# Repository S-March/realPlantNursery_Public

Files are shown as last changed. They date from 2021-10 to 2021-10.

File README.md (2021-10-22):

# realPlantNursery

## Plant Babies
plantBaby

I am REALLY bad at keeping plants alive. I killed a cactus by forgetting to water it once... 

These plant babies sit in the soil of your potted plants and cry like a real baby when they need water (reminding you not to kill them)!

## Tamagotchi mode
tamagotchiMode

Oh, I also made an app for them so you can turn on "tamagotchi" mode and check out all your plants stats!

## Other fun things

Come check out my youtube channel for more fun projects - [youtube.com/c/SamMarch](https://youtube.com/c/SamMarch)

For future projects and progress pictures, follow me on instagram @SamsonMarch

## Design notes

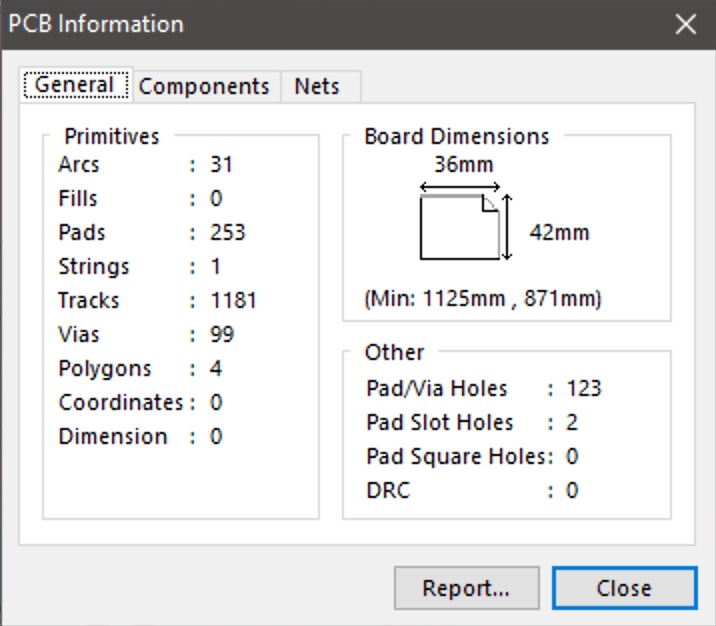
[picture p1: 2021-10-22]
Hardware/realPlantNursery/FabFiles/boardDimensions.jpg

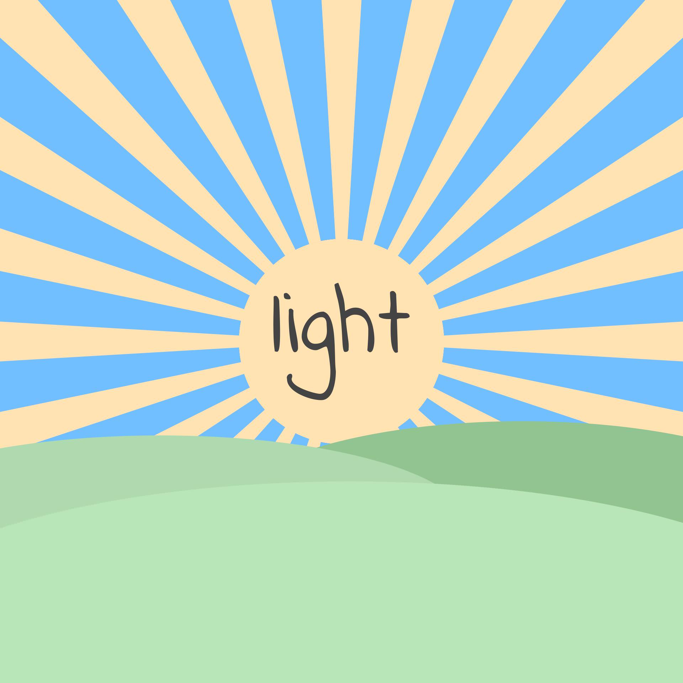
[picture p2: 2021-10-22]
Firmware/sdCardFiles/webPage/projects/lightPage/mediaAssets/imageAssets/main.jpg

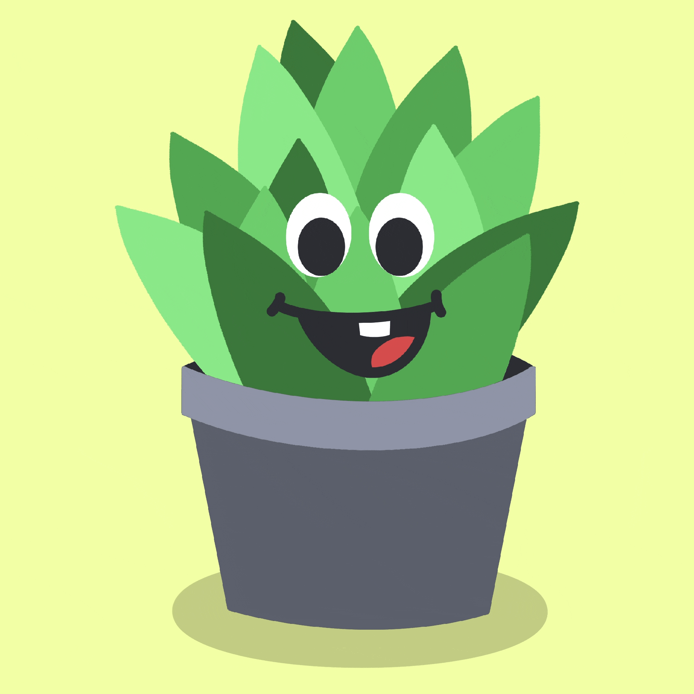
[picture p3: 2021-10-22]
Firmware/sdCardFiles/webPage/projects/mainPage/mediaAssets/imageAssets/main.gif

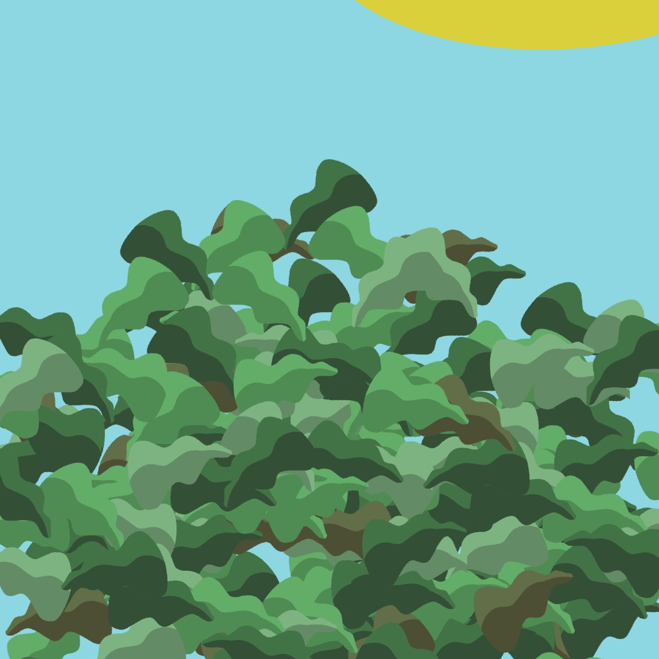
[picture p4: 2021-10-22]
Firmware/sdCardFiles/webPage/projects/lightPage/mediaAssets/imageAssets/lightPlot.jpg

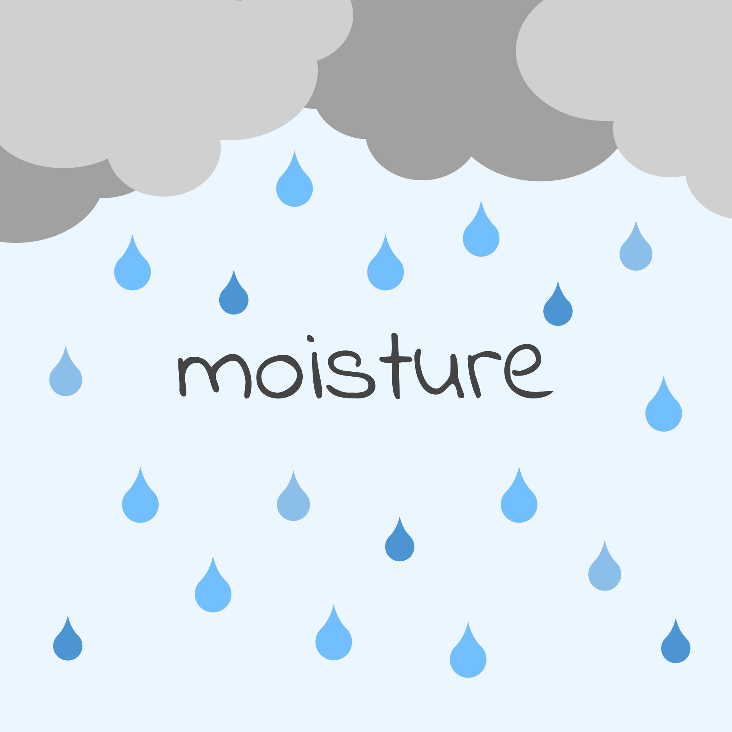
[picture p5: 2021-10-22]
Firmware/sdCardFiles/webPage/projects/moisturePage/mediaAssets/imageAssets/main.jpg

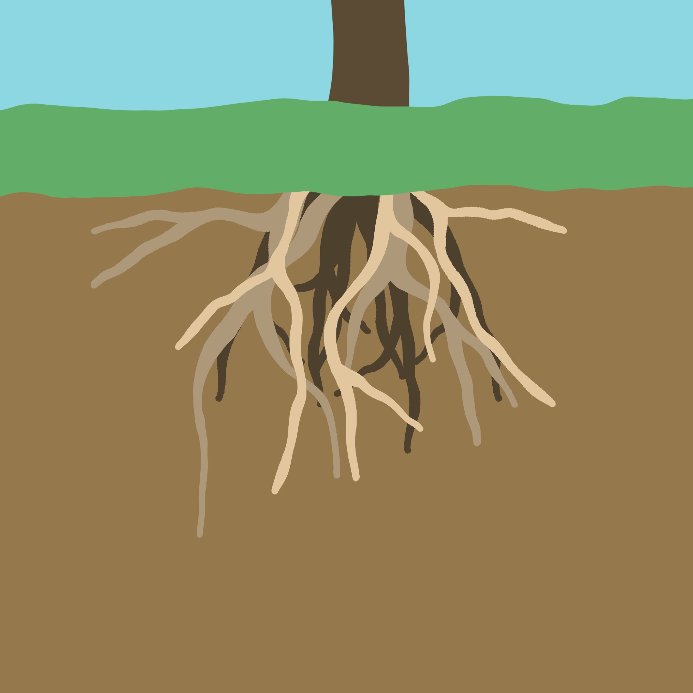
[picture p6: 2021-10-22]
Firmware/sdCardFiles/webPage/projects/moisturePage/mediaAssets/imageAssets/moisturePlot.jpg

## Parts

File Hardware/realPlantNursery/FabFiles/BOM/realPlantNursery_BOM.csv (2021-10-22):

Comment | Designator | Footprint | LCSC Part #（optional）
10k | R2, R4, R5, R6, R7, R8, R9, R10, R11, R12, R15, R16, R17, R18, R19, R20, R22, R23 | 0402_R | C25744
100nF | C2, C3, C4, C5, C7, C10, C15, C18, C19, C20 | 0402_C | C1525
10uF | C1, C6, C13 | 0603_C | C19702
22uF | C14, C16, C17 | 0603_C | C59461
SS34 | D2, D3, D4 | SMA | C408258
K2-1808SN-A4SW-01 | B1, B2 | SMD | C92589
4.7uF | C11, C12 | 0402_C | C23733
1M | R1, R24 | 0402_R | C26083
2450AT18D0100E | ANT1
WS2812B-B | D1 | LED-4_5050 | C114586
YNR3015-2R2M | L1 | SMD_3.0x3.0x1.5mm | C340359
VLS3015ET-3R3M | L2 | IND-SMD | C136236
DM3CS-SF | P1 | TF-SMD | C202111
MicroXNJ | P2 | SMD | C404969
AO3400A | Q1 | SOT-23-3L | C20917
AO3401A | Q2 | SOT-23-3L | C15127
2k | R13 | 0402_R | C4109
75k | R14 | 0402_R | C25798
1k | R21 | 0402_R | C11702
0 | R3 | 0402_R | C17168
MAX98357AETE+T | U1 | TQFN-16 | C910544
TXB0101DCKR | U2 | SC-70-6 | C324081
ESP32-PICO-D4 | U3 | QFN-48_EP_7.0x7.0x0.5P | C193707
TPS62082 | U4 | WDFN-8_EP_2.0x2.0x0.5P | C485809
MCP73832 | U5 | SOT-23-5 | C38066
FP6291LR-G1 | U6 | SOT-23-6L | C18701
BH1721FVC | U7 | WSOF-5 | C184130

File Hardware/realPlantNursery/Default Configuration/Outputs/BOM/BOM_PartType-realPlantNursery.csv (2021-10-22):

Quantity | Designator | Comment | Description
18 | R2, R4, R5, R6, R7, R8, R9, R10, R11, R12, R15, R16, R17, R18, R19, R20, R22, R23 | 10k | 0402 Resistor
10 | C2, C3, C4, C5, C7, C10, C15, C18, C19, C20 | 100nF | 0402 Capacitor
3 | C1, C6, C13 | 10uF | 0603 Capacitor
3 | C14, C16, C17 | 22uF | 0603 Capacitor
3 | D2, D3, D4 | SS34 | SS34 40V 3A 550mV @ 3A SMA(DO-214AC) Schottky Barrier Diodes (SBD) ROHS
2 | B1, B2 | K2-1808SN-A4SW-01 | K2-1808SN-A4SW-01 Tactile Switch SPST-NO Top Actuated Surface Mount
2 | C11, C12 | 4.7uF | 0402 Capacitor
2 | R1, R24 | 1M | 0402 Resistor
1 | ANT1 | 2450AT18D0100E | 2450AT18D0100E 2.4GHz Chip RF Antenna 2.4GHz ~ 2.5GHz 1.5dBi Solder Surface Mount
1 | D1 | WS2812B-B | WS2812B-B RGB 620~630nm Red, 515~530nm Green, 465~475nm Blue SMD,5x5mm Light Emitting Diodes (LED) ROHS
1 | L1 | YNR3015-2R2M | YNR3015-2R2M 2.2uH ±20% 1.6A 30mO SMD,3.0x3.0x1.5mm Power Inductors RoHS
1 | L2 | VLS3015ET-3R3M | VLS3015ET-3R3M 3.3 µH Shielded Wirewound Inductor 1.15 A 112mOhm Max Nonstandard
1 | P1 | DM3CS-SF | DM3CS-SF 10 (8 + 2) Position Card Connector Secure Digital - microSD™ Surface Mount, Right Angle Gold
1 | P2 | MicroXNJ | MicroXNJ USB - micro B USB 2.0 Receptacle Connector 5 Position Surface Mount, Right Angle; Through Hole
1 | Q1 | AO3400A | AO3400A N-Channel 30 V 5.7A (Ta) 1.4W (Ta) Surface Mount SOT-23-3
1 | Q2 | AO3401A | AO3401A MOSFET P-CH 30V 4A SOT23
1 | R13 | 2k | 0402 Resistor
1 | R14 | 75k | 0402 Resistor
1 | R21 | 1k | 0402 Resistor
1 | R3 | 0 | 0402 Resistor
1 | U1 | MAX98357AETE+T | MAX98357AETE+T Amplifier IC 1-Channel (Mono) Class D 16-TQFN (3x3)
1 | U2 | TXB0101DCKR | TXB0101DCKR Voltage Level Translator Bidirectional 1 Circuit 1 Channel 100Mbps SC-70-6
1 | U3 | ESP32-PICO-D4 | ESP32-PICO-D4 SoC
1 | U4 | TPS62082 | TPS62082 Buck Switching Regulator IC Positive Fixed 3.3V 1 Output 1.2A 8-WFDFN Exposed Pad
1 | U5 | MCP73832 | MCP73831 Charger IC Lithium-Ion/Polymer
1 | U6 | FP6291LR-G1 | FP6291LR-G1 2A 5.5V SOT-23-6 DC-DC Converters ROHS
1 | U7 | BH1721FVC | BH1721FVC Optical Sensor Ambient 560nm I²C 5-SMD, Flat Leads

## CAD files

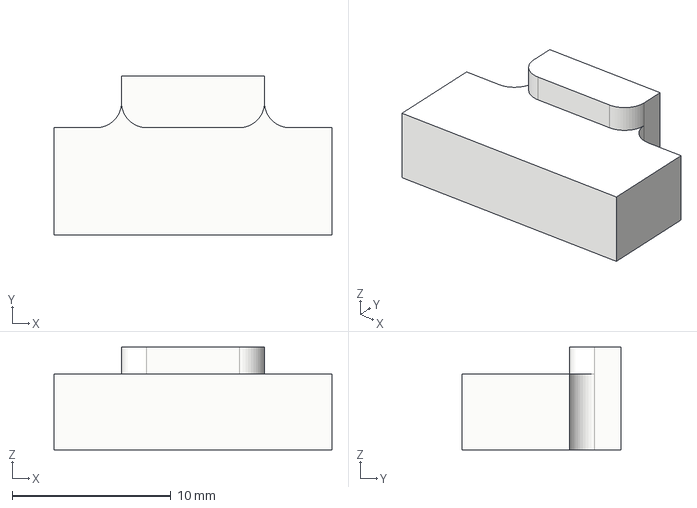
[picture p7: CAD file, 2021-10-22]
CAD/preManufacturing/usbRetainer.step
17.5 x 10.0 x 6.47 mm

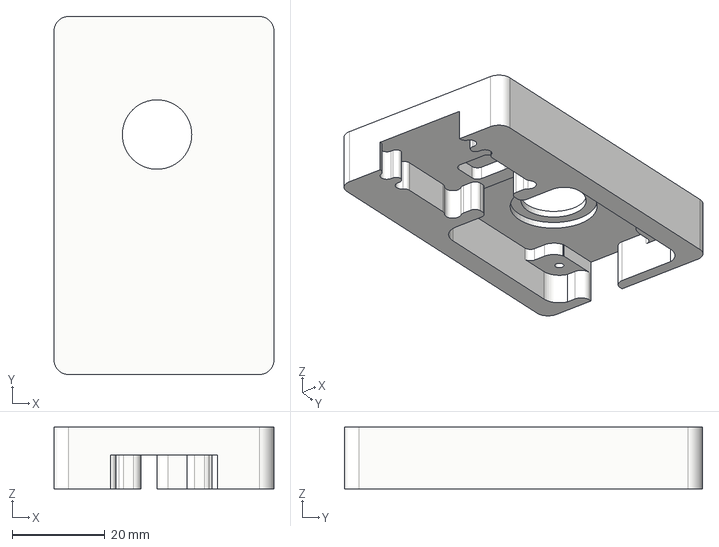
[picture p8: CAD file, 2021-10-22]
CAD/preManufacturing/frontPlate.step
47.5 x 77.3 x 13.3 mm

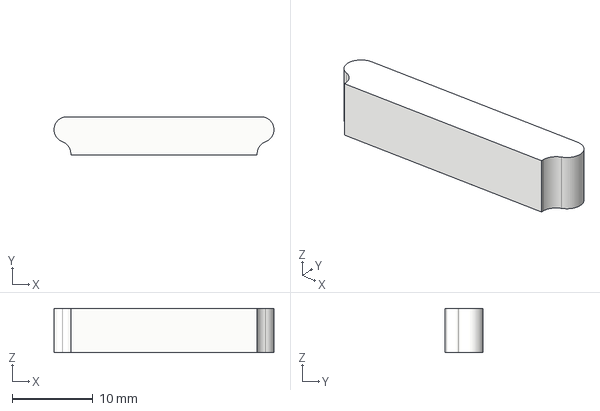
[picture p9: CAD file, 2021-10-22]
CAD/preManufacturing/moistureSensorRetainer.step
27.3 x 4.75 x 5.48 mm

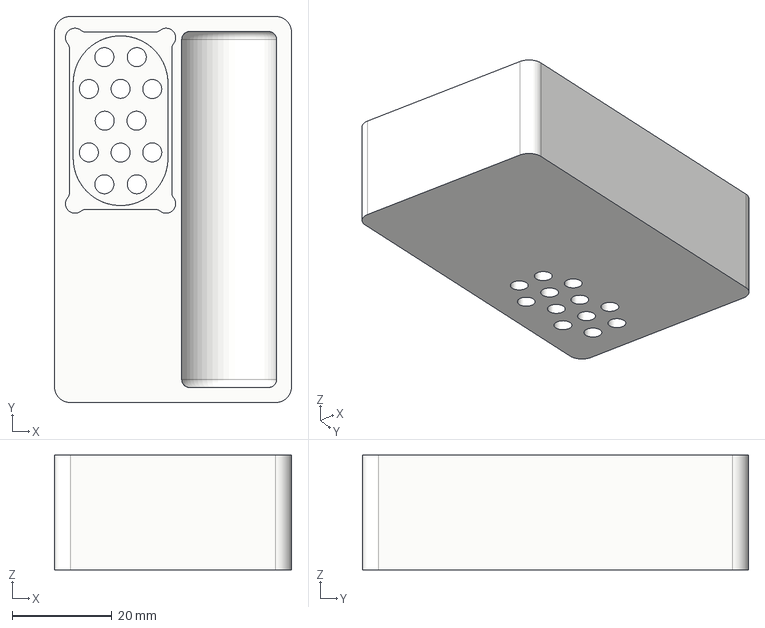
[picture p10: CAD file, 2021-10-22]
CAD/preManufacturing/backPlate.step
47.5 x 77.3 x 23.0 mm

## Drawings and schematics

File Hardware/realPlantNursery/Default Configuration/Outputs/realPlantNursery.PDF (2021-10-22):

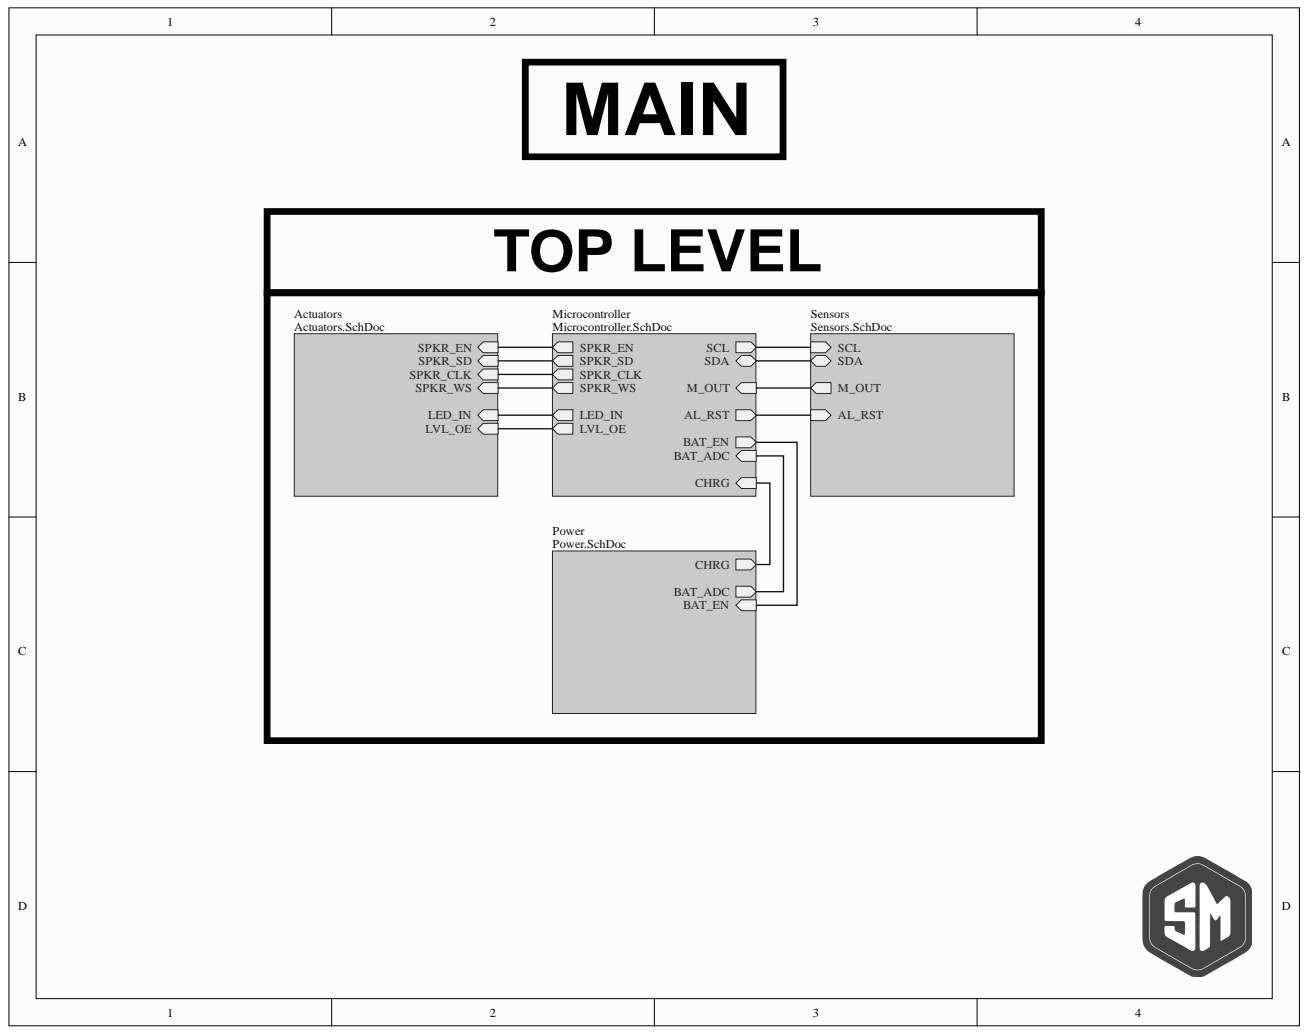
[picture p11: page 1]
TOP LEVEL

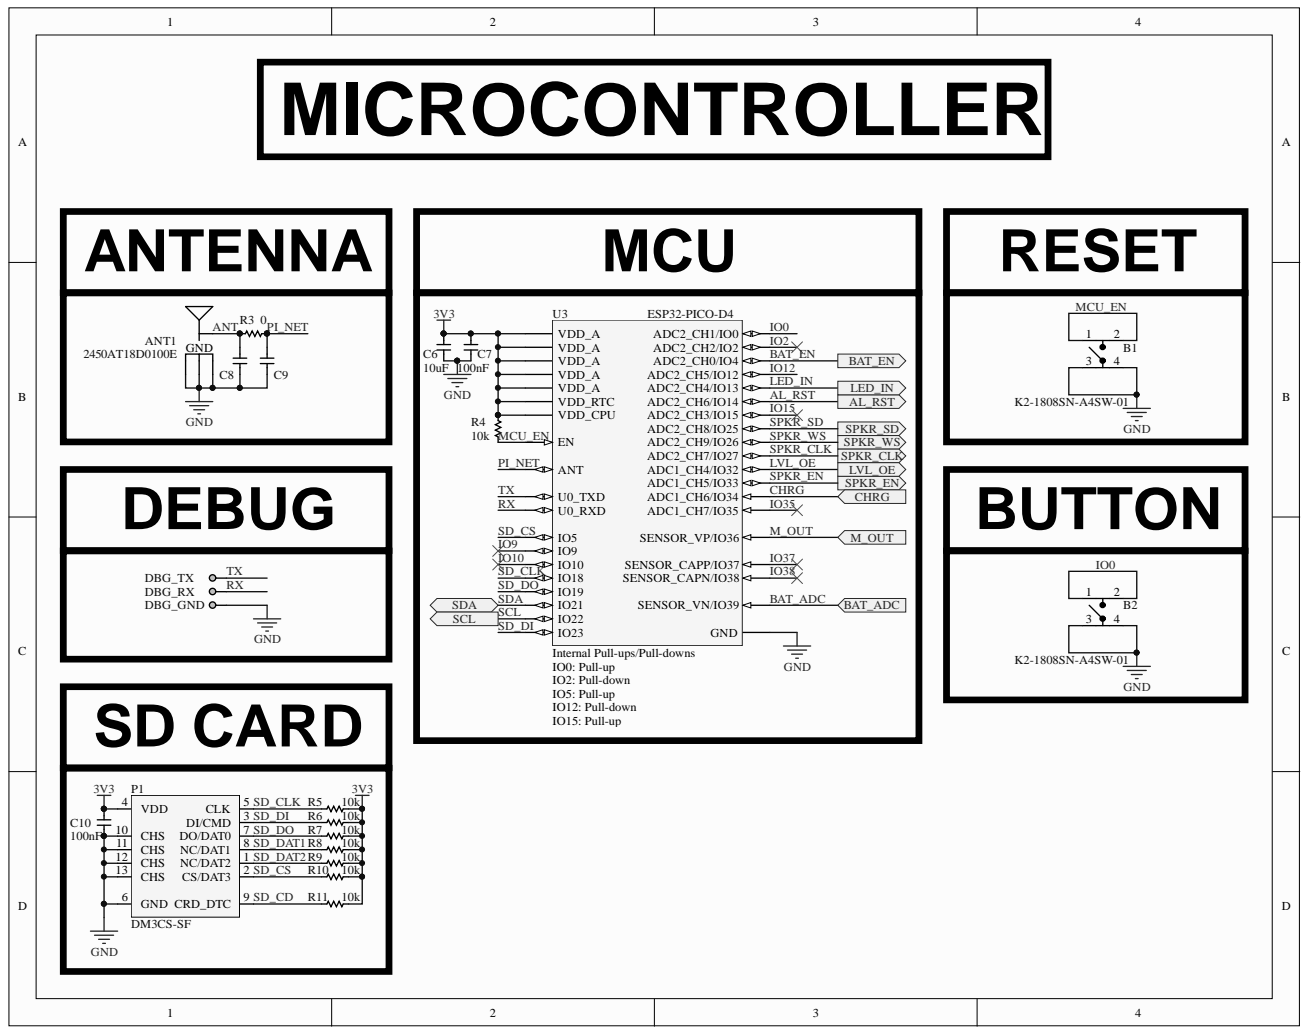
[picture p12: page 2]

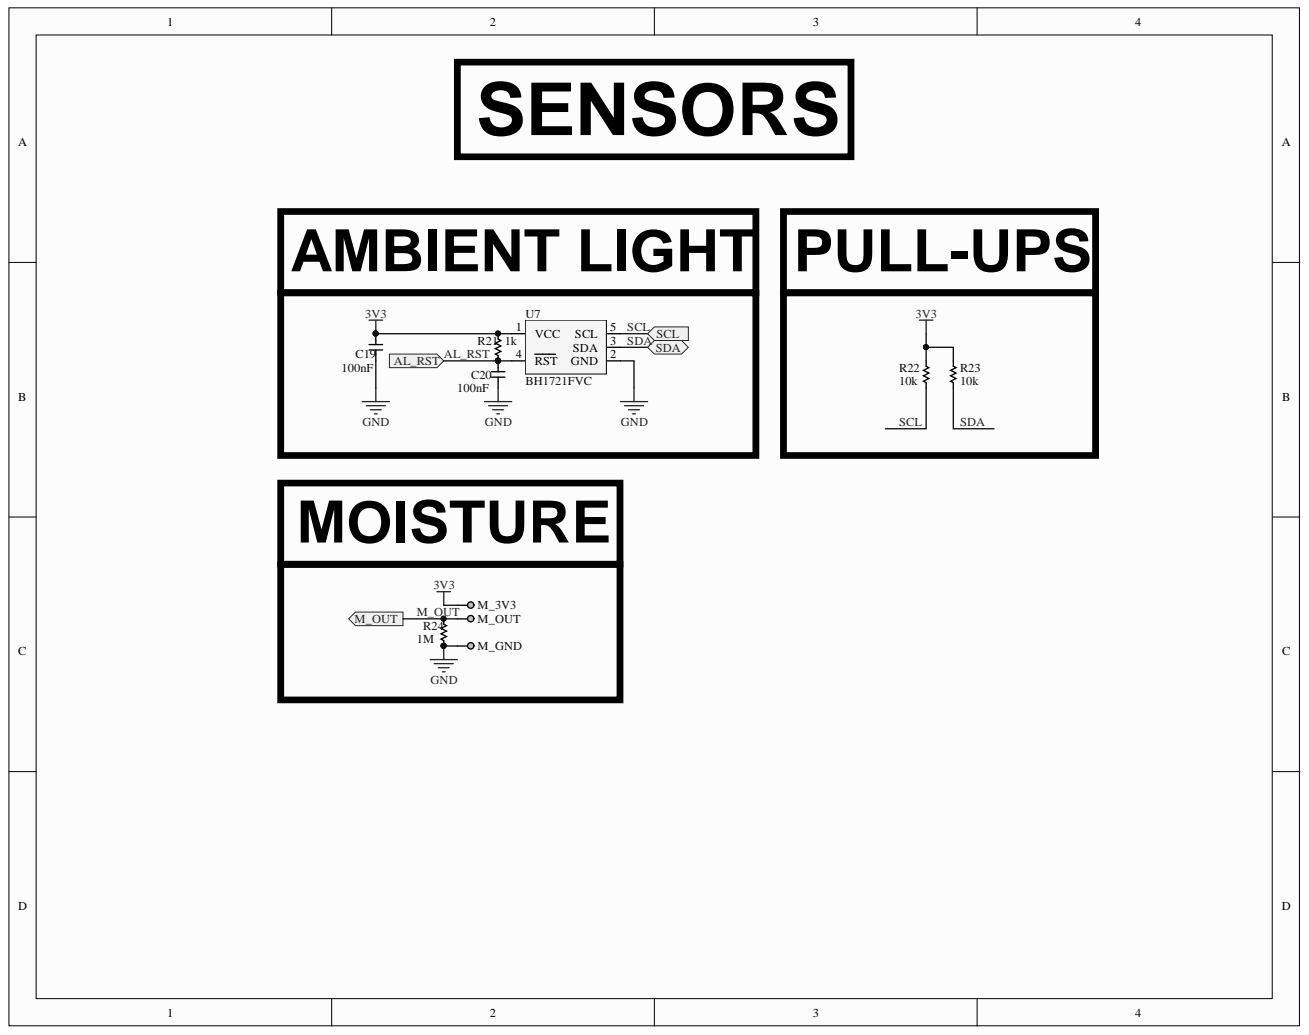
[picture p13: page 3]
AMBIENT LIGHT; SCL SCL; SDA; AL_RST AL_RST; VCC 1; GND; 2 SDA; RST 4; M_OUT; M_OUT R24

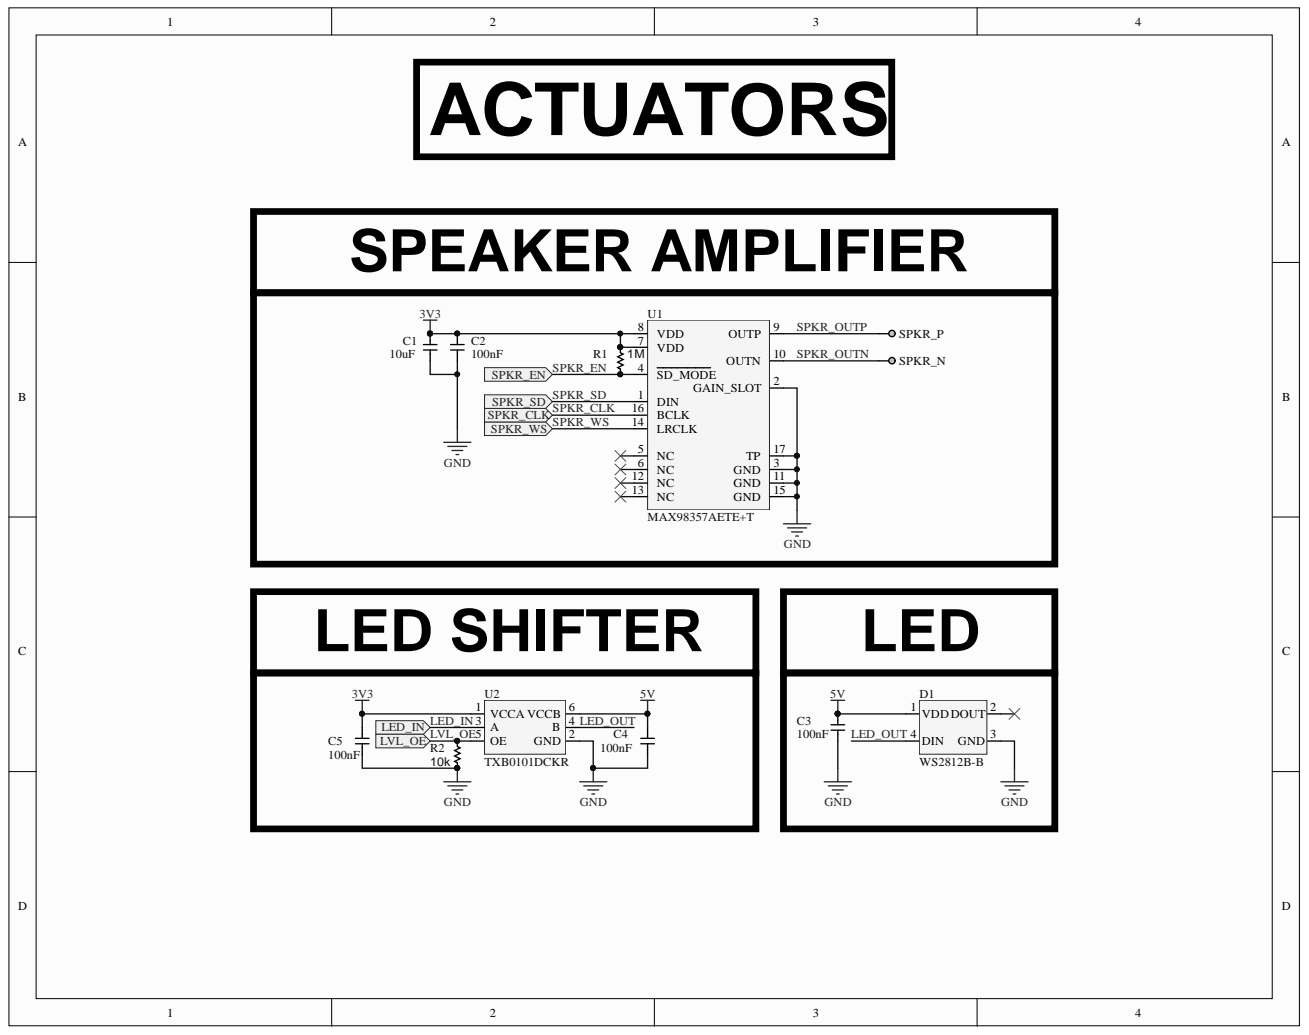
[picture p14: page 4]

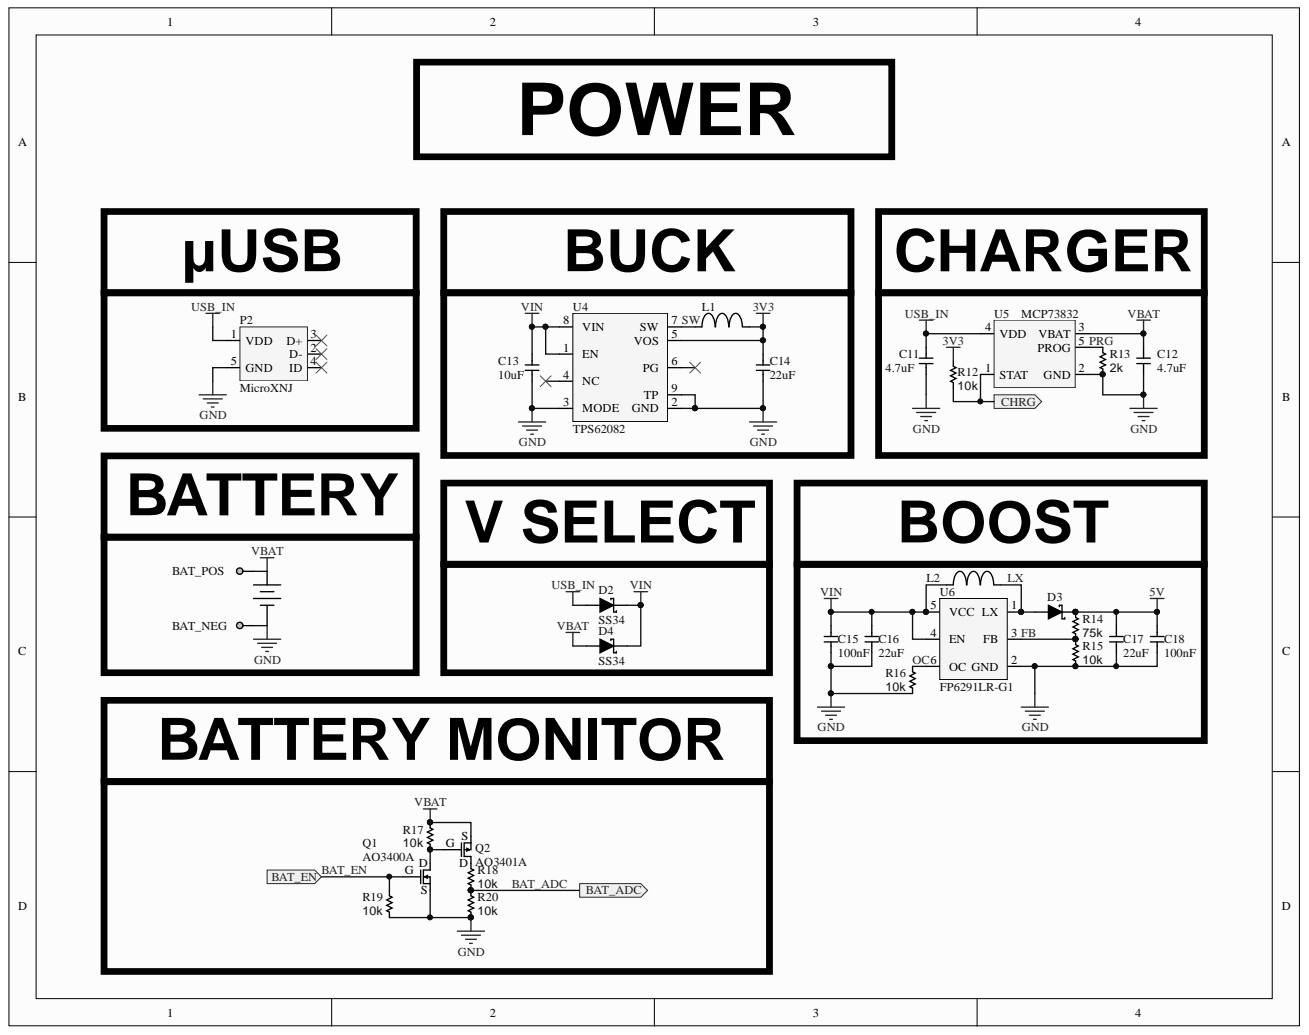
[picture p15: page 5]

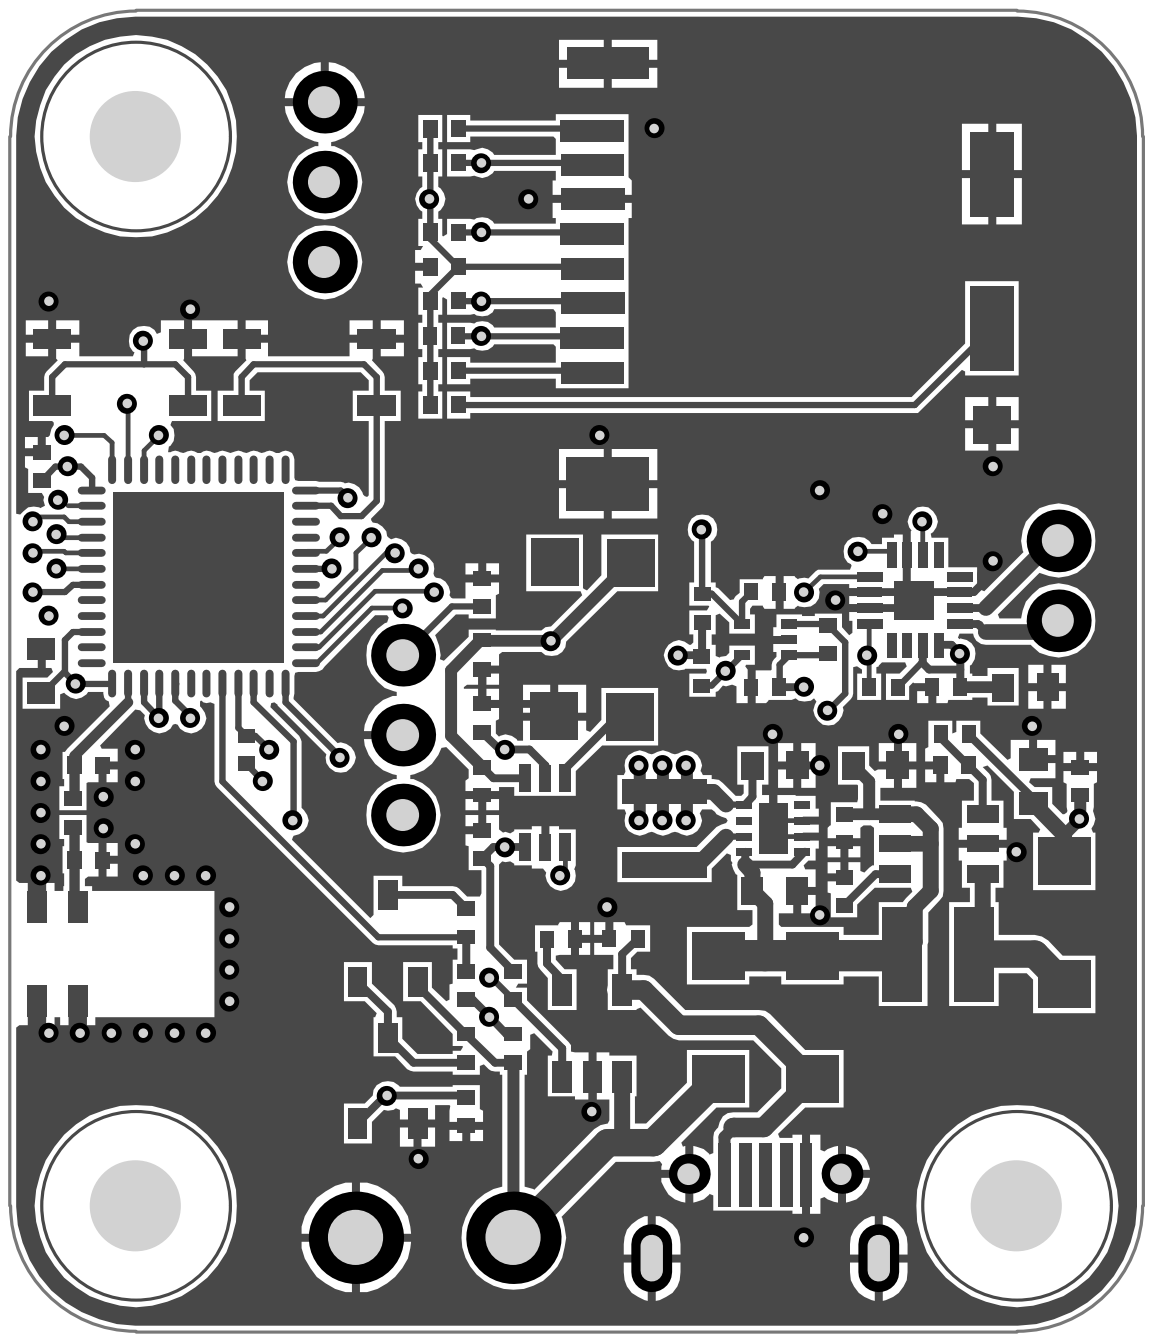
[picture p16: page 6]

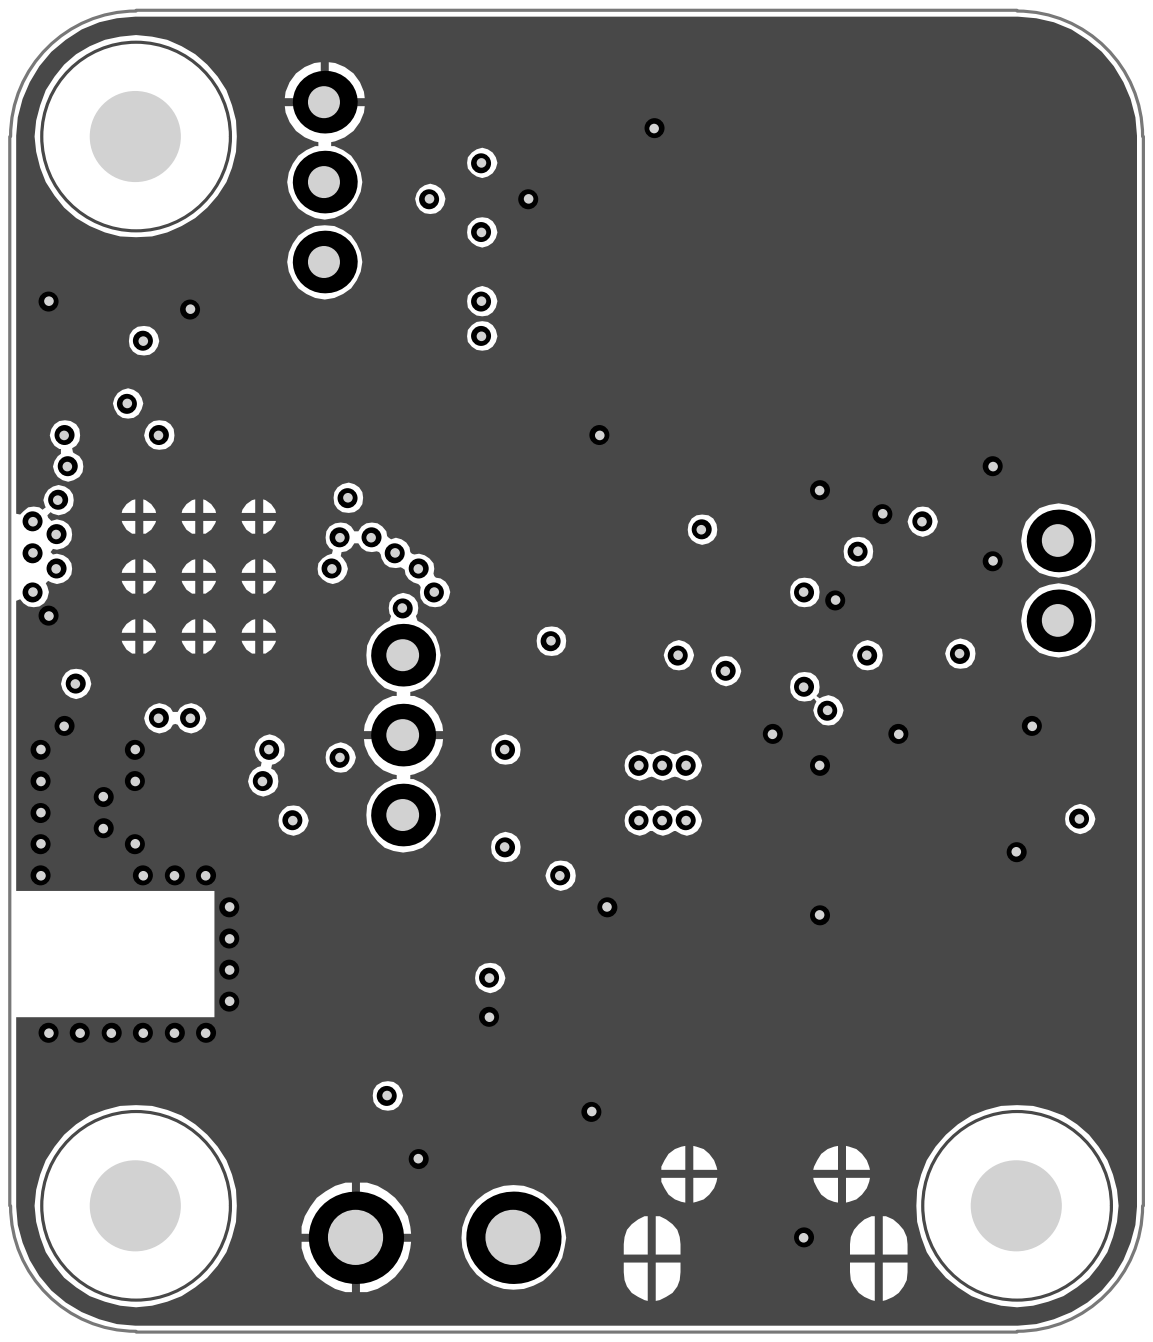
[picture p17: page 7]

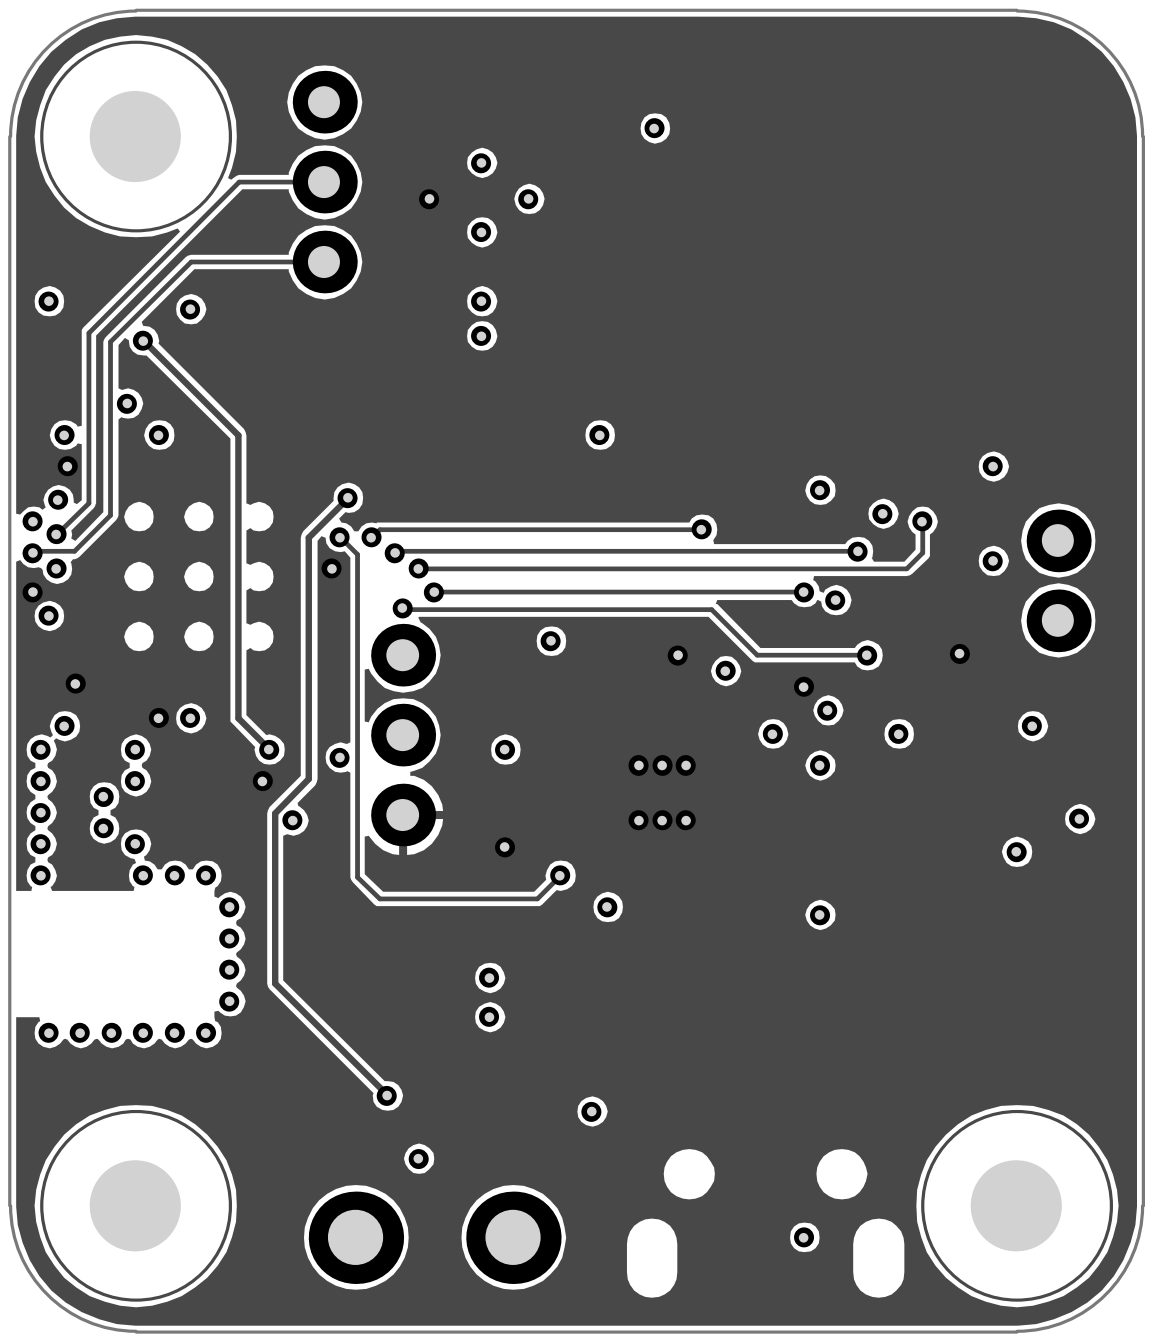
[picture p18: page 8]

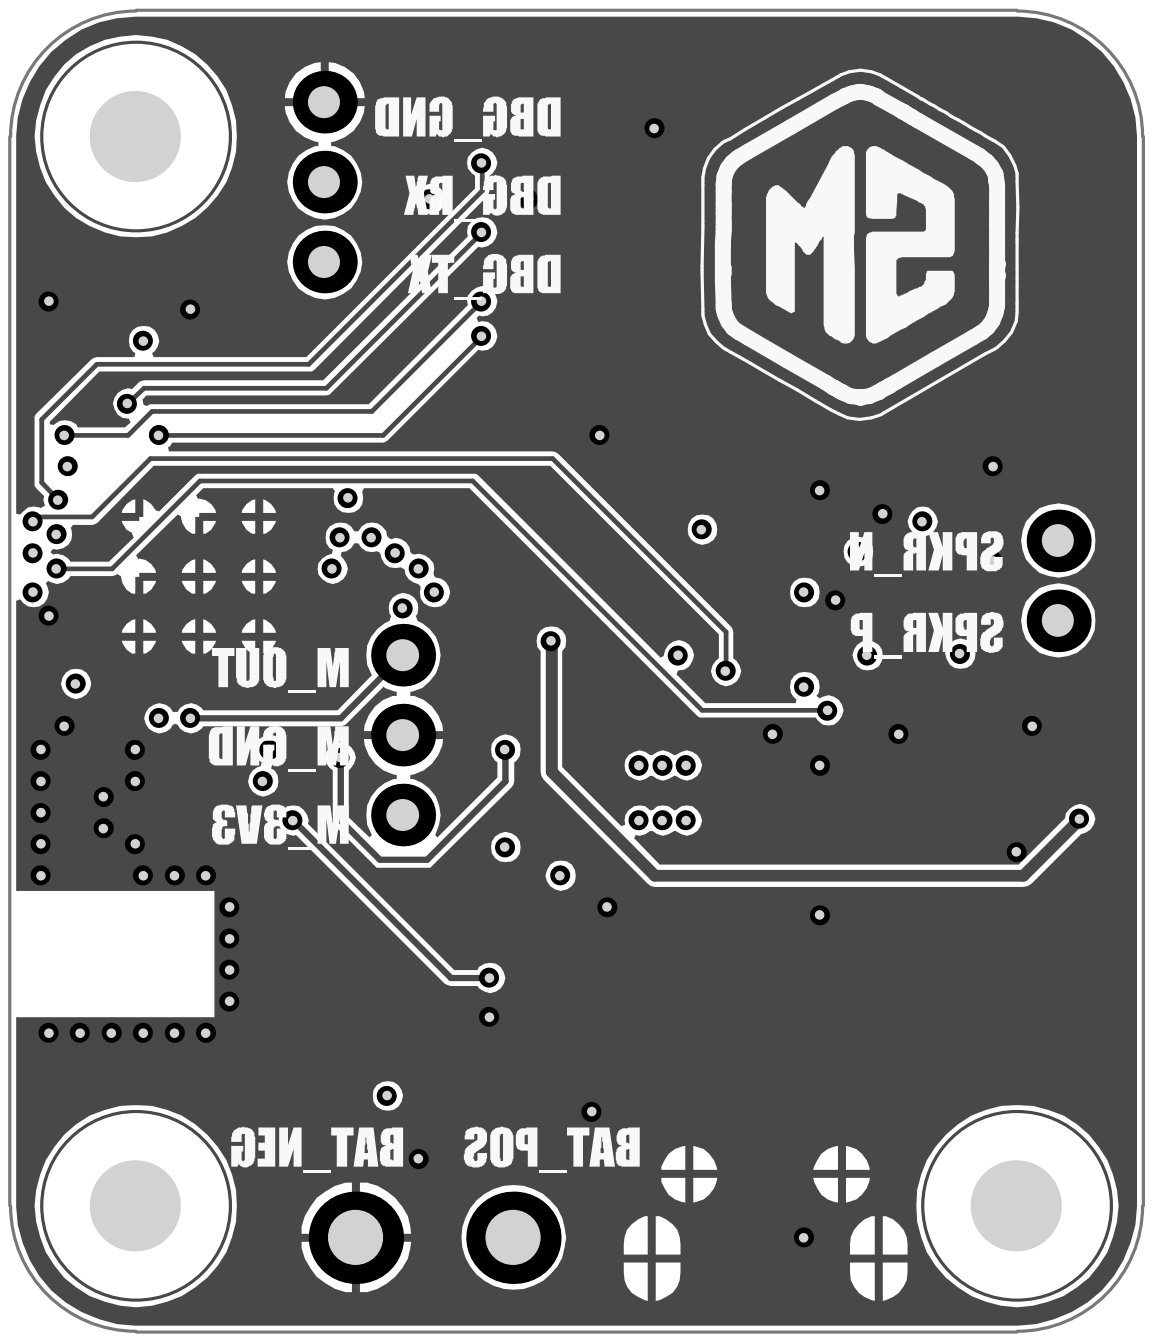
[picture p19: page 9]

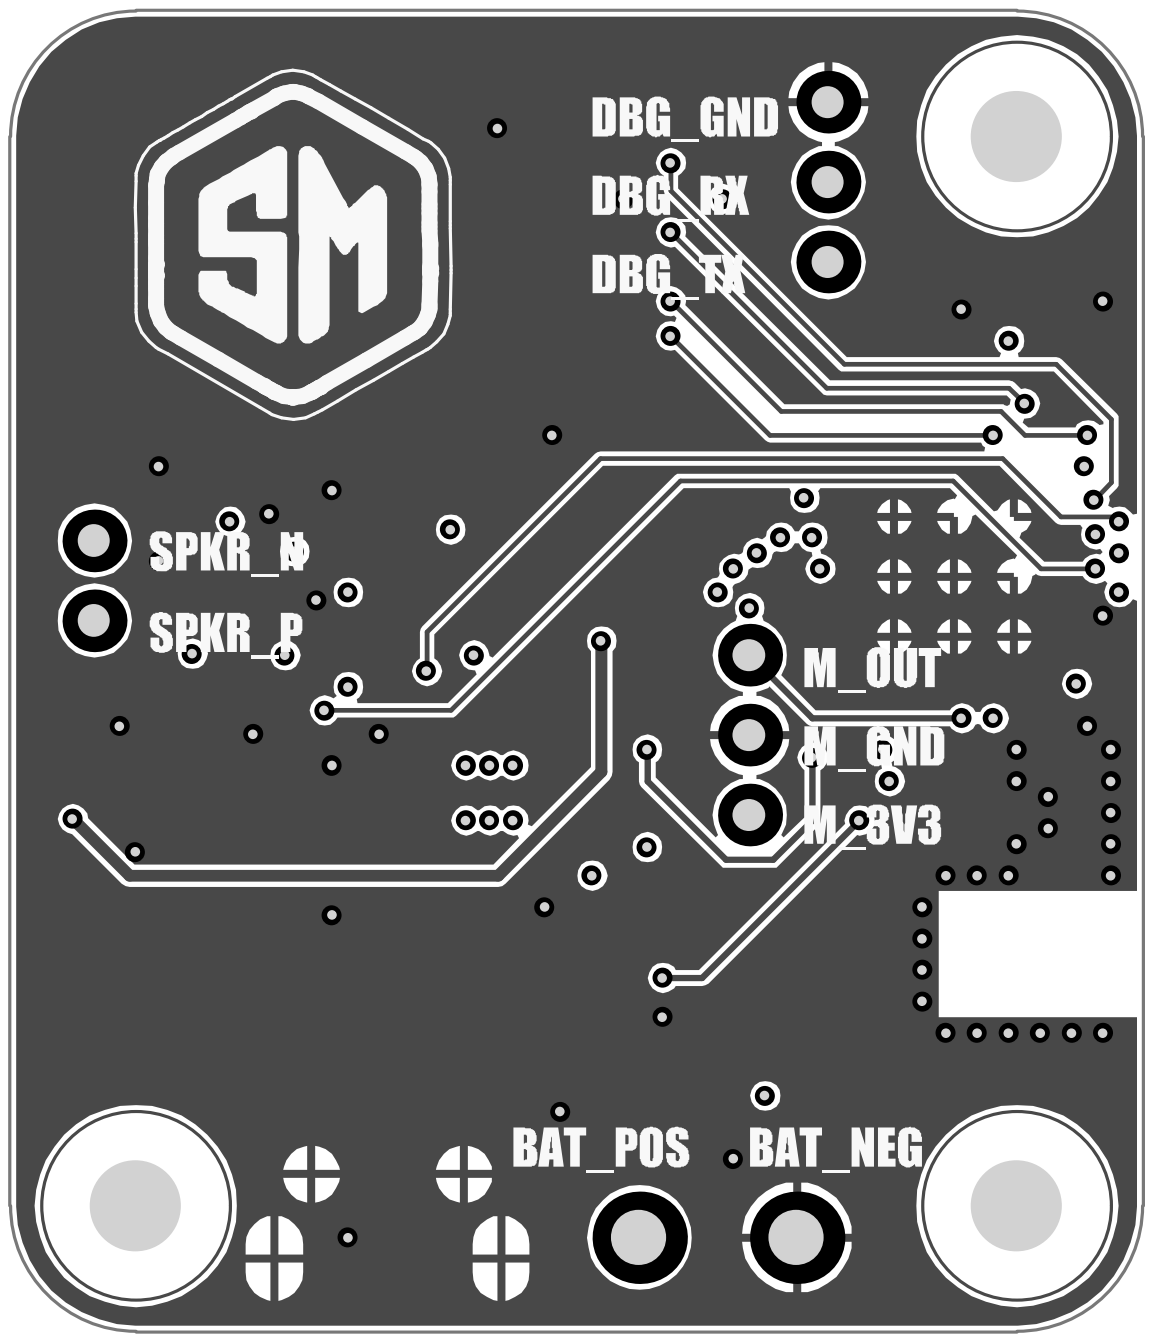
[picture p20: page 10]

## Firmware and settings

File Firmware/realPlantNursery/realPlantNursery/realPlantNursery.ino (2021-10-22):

//////////////////////
// realPlantNursery //
// by Sam March     //
//////////////////////

///////////////
// Libraries //
///////////////
#include "Arduino.h"
#include <Wire.h>
#include "BH1721FVC.h"
#include <FastLED.h>                  //Credit: https://github.com/FastLED/FastLED
#include <DNSServer.h>
#include <WiFi.h>
#include "AsyncTCP.h"
#include "ESPAsyncWebServer.h"        //Credit: https://github.com/me-no-dev/ESPAsyncWebServer
#include "FS.h"
#include "SD.h"
#include "Audio.h"                    //Credit: https://github.com/schreibfaul1/ESP32-audioI2S

/////////////
// Defines //
/////////////
/********************
   Moisture Sensing
 ********************/
#define MOISTURE_SENSOR_PIN           36
#define MOISTURE_SENSOR_POWER_PIN     3
#define CALIBRATION_SAMPLE_SIZE       64
/*************************
   Ambient Light Sensing
 *************************/
#define AMBIENT_LIGHT_RST_PIN         14
#define AMBIENT_LIGHT_MAX             15000//65528
/***********
   Battery
 ***********/
#define BATTERY_MEASURE_EN_PIN        4
#define BATTERY_MEASURE_PIN           39
#define BATTERY_CHARGE_PIN            34
#define BAT_CHECK_TIME_INTERVAL       1000
#define BAT_ADC_MAX                   2450
#define BAT_ADC_MIN                   1680
/*******
   LED
 *******/
#define LED_DATA_PIN                 13
#define LED_LEVEL_SHIFTER_EN_PIN     32
/***********
   SD Card
 ***********/
#define SD_CARD_CS_PIN                5
#define SD_CARD_DI_PIN                23
#define SD_CARD_DO_PIN                19
#define SD_CARD_CLK_PIN               18
/*******************
   Audio Amplifier
 *******************/
#define I2S_SD_PIN                    25
#define I2S_BCLK_PIN                  27
#define I2S_WS_PIN                    26
#define I2S_EN_PIN                    33
/**********
   Timing
 **********/
#define MOISTURE_CHECK_TIME_INTERVAL  1000
#define AL_CHECK_TIME_INTERVAL        1000
#define SLEEP_TIMEOUT_INTERVAL        1000
#define SLEEP_TIME_IN_SECONDS         60
#define SLEEP_TIME_IN_MINUTES         3600000000//60*60*1000*1000
#define BUTTON_DEBOUNCE_TIME          1000
#define WIFI_ON_TIME_MINUTES          10
#define WIFI_ON_TIMEOUT               WIFI_ON_TIME_MINUTES*60*1000
/*********
   Button
 *********/
#define USER_BUTTON_PIN               0
/*********
   Debug
 *********/
#define DEBUG_MODE                    1

///////////////////////////
// Function Declarations //
///////////////////////////
int moistureSensorCalibration(int CURRENT_STEP);
int moistureSensorReadAverage(int NUMBER_OF_SAMPLES_TO_AVERAGE);
void moistureSensorHandler(void);
void ambientLightSensorHandler(void);
void batteryMonitorHandler(void);
int batteryMonitorReadAverage(int NUMBER_OF_SAMPLES_TO_AVERAGE);
void setLedRGB(uint8_t RED, uint8_t GREEN, uint8_t BLUE);
void audioHandler(void);
void playAudioFile(String FILENAME, uint8_t RED, uint8_t GREEN, uint8_t BLUE);
void sleepHandler(void);
void wifiTaskHandler(void);
void buttonHandler(void);
void deleteFile(fs::FS &fs, const char * path);
void appendFile(fs::FS &fs, const char * path, const char * message);
void readFile(fs::FS &fs, const char * path);
bool readSettingsData(fs::FS &fs, const char * path);
void writeDefaultSettingsData(fs::FS &fs, const char * path);
bool readCalibrationData(fs::FS &fs, const char * path);
void onEvent(AsyncWebSocket * server, AsyncWebSocketClient * client, AwsEventType type, void * arg, uint8_t *data, size_t len);
void parseWebsocketsData(String MESSAGE);

///////////////
// Variables //
///////////////
/**********************
   Moisture Variables
 **********************/
int currentMoisture;
int moistureCalibrationStep;
RTC_DATA_ATTR int moistureThreshold;
bool updateCalibration;
bool firstMoistureMeasurement;
/***************************
   Ambient Light Variables
 ***************************/
int currentLight;
RTC_DATA_ATTR int lightThreshold;
bool firstLightMeasurement;
/*****************
   LED Variables
 *****************/
CRGB leds[1];
/*********************
   Battery Variables
 *********************/
int batteryMonitorCheckTime;
int currentBattery;
RTC_DATA_ATTR int batteryThreshold;
bool firstBatteryMeasurement;
/*******************
   Audio Variables
 *******************/
Audio audioAmp;
bool needWaterAlert;
RTC_DATA_ATTR int silentMode;
/********************
   Timing Variables
 ********************/
int currentTime;
int moistureCheckTime;
int ambientLightCheckTime;
int buttonPressTime;
int wifiTimeoutTime;
/*******************
   Sleep Variables
 *******************/
RTC_DATA_ATTR bool isCalibrated         = false;
RTC_DATA_ATTR bool loadSettingsData     = true;
RTC_DATA_ATTR int lowerCalibrationBound;
RTC_DATA_ATTR int upperCalibrationBound;
RTC_DATA_ATTR int calibrationRange;
bool readyToSleep;
esp_sleep_wakeup_cause_t wakeupSource;
/*******************
   WiFi Variables
 *******************/
bool wifiRequired;
bool wifiInitialized;
DNSServer dnsServer;
AsyncWebServer server(80);
AsyncWebSocket ws("/ws");
String webSocketData;
class captivePageHandler : public AsyncWebHandler
{
  public:
    captivePageHandler()
    {
      server.on("/", HTTP_GET, [](AsyncWebServerRequest * request)
      {
        request->send(SD, "/webPage/index.html", "text/html");
      });
      server.onNotFound([](AsyncWebServerRequest * request)
      {
        request->send(SD, "/webPage/index.html", "text/html");
      });
      server.serveStatic("/", SD, "/webPage/");
    }
    bool canHandle(AsyncWebServerRequest *request)
    {
      return true;
    }
    void handleRequest(AsyncWebServerRequest *request)
    {
      request->send(SD, "/webPage/index.html", "text/html");
      server.serveStatic("/", SD, "/webPage/");
    }
};
/********************
   Button Variables
 ********************/
bool buttonDebouncing;
struct buttonStruct
{
  const uint8_t PIN;
  bool buttonPressed;
};
buttonStruct userButtonSwitch = {USER_BUTTON_PIN, false};
void IRAM_ATTR userButtonSwitchISR()
{
  userButtonSwitch.buttonPressed = true;
}

////////////////////
// Initialization //
////////////////////
void setup()
{
  /***********************
     UART Initialization
   ***********************/
  Serial.begin(115200);
  Serial.println("Booting");
  /**************************
     SD Card Initialization
   **************************/
  pinMode(SD_CARD_CS_PIN, OUTPUT);
  digitalWrite(SD_CARD_CS_PIN, HIGH);
  SPI.begin(SD_CARD_CLK_PIN, SD_CARD_DO_PIN, SD_CARD_DI_PIN);
  SD.begin(SD_CARD_CS_PIN);
  /************************
     Audio Initialization
   ************************/
  pinMode(I2S_EN_PIN, OUTPUT);
  audioAmp.setPinout(I2S_BCLK_PIN, I2S_WS_PIN, I2S_SD_PIN);
  audioAmp.setVolume(21);
  silentMode = 0;
  /***********************
     WiFi Initialization
   ***********************/
  wifiRequired              = false;
  wifiInitialized           = false;
  webSocketData             = "";
  /***************************
     Moisture Initialization
   ***************************/
  currentMoisture           = 0;
  moistureCalibrationStep   = 0;
  updateCalibration         = false;
  firstMoistureMeasurement  = true;
  needWaterAlert            = false;
  /********************************
     Ambient Light Initialization
   ********************************/
  Wire.begin();
  al_initializeSensor(AMBIENT_LIGHT_RST_PIN);
  currentLight              = 0;
  firstLightMeasurement     = true;
  /*************************
     Timing Initialization
   *************************/
  currentTime               = 0;
  moistureCheckTime         = 0;
  ambientLightCheckTime     = 0;
  buttonPressTime           = 0;
  /*************************
     Button Initialization
   *************************/
  pinMode(USER_BUTTON_PIN, INPUT_PULLUP);
  attachInterrupt(USER_BUTTON_PIN, userButtonSwitchISR, FALLING);
  buttonDebouncing          = false;
  /**************************
     Battery Initialization
   **************************/
  pinMode(BATTERY_MEASURE_EN_PIN, OUTPUT);
  digitalWrite(BATTERY_MEASURE_EN_PIN, LOW);
  batteryMonitorCheckTime   = 0;
  currentBattery            = 0;
  firstBatteryMeasurement   = true;
  /**********************
     LED Initialization
   **********************/
  LEDS.addLeds<WS2812, LED_DATA_PIN, GRB>(leds, 1);
  LEDS.setBrightness(250);
  pinMode(LED_LEVEL_SHIFTER_EN_PIN, OUTPUT);
  digitalWrite(LED_LEVEL_SHIFTER_EN_PIN, LOW);
  /************************
     Sleep Initialization
   ************************/
  readyToSleep              = false;
  esp_sleep_enable_timer_wakeup(SLEEP_TIME_IN_MINUTES);
  esp_sleep_enable_ext0_wakeup(GPIO_NUM_0, 0);
  wakeupSource = esp_sleep_get_wakeup_cause();
  if (wakeupSource == ESP_SLEEP_WAKEUP_EXT0)
  {
    wifiRequired = true;
  }
  /***************************
     Settings Initialization
   ***************************/
  if (loadSettingsData)
  {
    moistureThreshold         = 25;
    lightThreshold            = 25;
    batteryThreshold          = 25;
    if (!readSettingsData(SD, "/webPage/savedSettings.txt"))
    {
      writeDefaultSettingsData(SD, "/webPage/savedSettings.txt");
    }
    loadSettingsData = false;
  }
}

///////////////
// Main Loop //
///////////////
void loop() {
  currentTime = millis();
  /******************
     Moisture Tasks
   ******************/
  moistureSensorHandler();
  /***********************
     Ambient Light Tasks
   ***********************/
  ambientLightSensorHandler();
  /***************
     Audio Tasks
   ***************/
  audioAmp.loop();
  /**************
     WiFi Tasks
   **************/
  wifiTaskHandler();
  /****************
     Button Tasks
   ****************/
  buttonHandler();
  /****************
     Battery Tasks
   ****************/
  batteryMonitorHandler();
  /***************
     Sleep Tasks
   ***************/
  sleepHandler();
}

//////////////////////////
// Function Definitions //
//////////////////////////
/*************************************************************
   Function: int moistureSensorCalibration(int CURRENT_STEP)
   Summary: The function walks the user through calibrating
   the sensor with audio queues
   Input: Current position in the calibration process
   Output: Next step in the calibration process
 *************************************************************/
int moistureSensorCalibration(int CURRENT_STEP)
{
  int upperReading = 0;
  int lowReading = 0;
  int nextStepToComplete = 0;
  char dataToSaveUpper[10] = {0};
  char dataToSaveLower[10] = {0};
  switch (CURRENT_STEP)
  {
    case 0:
      Serial.println("Calibration step 0:");
      Serial.println("Announcing calibration start, requesting air sample");
      //      audioAmp.connecttoFS(SD, "audioFiles/calibrationRequestAir.mp3");
      playAudioFile("audioFiles/calibrationRequestAir.mp3", 184, 211, 255);
      nextStepToComplete = 1;
      break;
    case 1:
      Serial.println("Calibration step 1:");
      Serial.println("Taking air sample");
      upperCalibrationBound = moistureSensorReadAverage(CALIBRATION_SAMPLE_SIZE);
      Serial.print("Air value: ");
      Serial.println(upperCalibrationBound);
      nextStepToComplete = 2;
      break;
    case 2:
      Serial.println("Calibration step 2:");
      Serial.println("Announcing end of air sample, requesting water sample");
      //      audioAmp.connecttoFS(SD, "audioFiles/calibrationRequestWater.mp3");
      playAudioFile("audioFiles/calibrationRequestWater.mp3", 36, 129, 255);
      nextStepToComplete = 3;
      break;
    case 3:
      Serial.println("Calibration step 3:");
      Serial.println("Taking water sample");
      lowerCalibrationBound = moistureSensorReadAverage(CALIBRATION_SAMPLE_SIZE);
      Serial.print("Water value: ");
      Serial.println(lowerCalibrationBound);
      nextStepToComplete = 4;
      break;
    case 4:
      Serial.println("Calibration step 4:");
      Serial.println("Calibration over");
      //      audioAmp.connecttoFS(SD, "audioFiles/calibrationOver.mp3");
      playAudioFile("audioFiles/calibrationOver.mp3", 51, 227, 45);
      calibrationRange = upperCalibrationBound - lowerCalibrationBound;
      nextStepToComplete = 0;
      deleteFile(SD, "/calibrationData.txt");
      appendFile(SD, "/calibrationData.txt", "C1");
      appendFile(SD, "/calibrationData.txt", "U");
      appendFile(SD, "/calibrationData.txt",  itoa(upperCalibrationBound, dataToSaveUpper, 10));
      appendFile(SD, "/calibrationData.txt", "L");
      appendFile(SD, "/calibrationData.txt", itoa(lowerCalibrationBound, dataToSaveLower, 10));
      appendFile(SD, "/calibrationData.txt", "E");
      isCalibrated = true;
      updateCalibration = false;
      break;
    default:
      break;
  }
  return nextStepToComplete;
}
/******************************************************************************
   Function: int moistureSensorReadAverage(int NUMBER_OF_SAMPLES_TO_AVERAGE)
   Summary: The function takes a number of samples and averages them together
   Input: The total number of samples to average
   Output: The averaged of the samples taken
 ******************************************************************************/
int moistureSensorReadAverage(int NUMBER_OF_SAMPLES_TO_AVERAGE)
{
  int avgMoistureReading = 0;
  for (int i = 0; i < NUMBER_OF_SAMPLES_TO_AVERAGE; i++)
  {
    avgMoistureReading += analogRead(MOISTURE_SENSOR_PIN);
  }
  avgMoistureReading /= NUMBER_OF_SAMPLES_TO_AVERAGE;
  return avgMoistureReading;
}
/**********************************************
   Function: void moistureSensorHandler(void)
   Summary: The function handles the moisture
   sensor related tasks
   Input: None
   Output: None
 **********************************************/
void moistureSensorHandler(void)
{
  //Check to see if the sensor is calibrated
  if (isCalibrated)
  {
    if ((currentTime - moistureCheckTime) > MOISTURE_CHECK_TIME_INTERVAL)
    {
      currentMoisture = 0;
      //Collect samples
      currentMoisture = moistureSensorReadAverage(CALIBRATION_SAMPLE_SIZE);
      //Map the samples to percent based on calibrated data
      currentMoisture = map(currentMoisture, lowerCalibrationBound, upperCalibrationBound, 0, 100);
      //Subtract the percent from 100 in order to indicate 0 = dry, 100 = water
      currentMoisture = 100 - currentMoisture;
      //Make sure the percent is within 0 to 100 percent
      if (currentMoisture < 0)
      {
        currentMoisture = 0;
      }
      if (currentMoisture > 100)
      {
        currentMoisture = 100;
      }
      Serial.print("Moisture: ");
      Serial.println(currentMoisture);
      if (firstMoistureMeasurement)
      {
        char moistureDataToSave[10] = {0};
        appendFile(SD, "/webPage/measuredData/moistureData.txt",  itoa(currentMoisture, moistureDataToSave, 10));
        appendFile(SD, "/webPage/measuredData/moistureData.txt", "\n");
        firstMoistureMeasurement = false;
      }
      //Only alert if wifi isn't on
      if(!wifiRequired)
      {        
        //If the moisture is below the threshold, start crying for water
        if (currentMoisture < moistureThreshold)
        {
          if (!audioAmp.isRunning())
          {
            playAudioFile("audioFiles/needWater.mp3", 100, 100, 100);
            needWaterAlert = true;
          }
        }
        else
        {
          //If crying is ongoing but moisture is now at good levels, burp
          if (needWaterAlert && !audioAmp.isRunning())
          {
            playAudioFile("audioFiles/waterGood.mp3", 100, 100, 100);
            needWaterAlert = false;
          }
          //If crying has stopped and moisture is at a good level, go to sleep
          if (!needWaterAlert && !audioAmp.isRunning())
          {
            readyToSleep = true;
          }
        }
      }
      moistureCheckTime = currentTime;
    }
  }
  //If the sensor is not calibrated, calibrate first
  else
  {
    if (!updateCalibration)
    {
      if (readCalibrationData(SD, "/calibrationData.txt"))
      {
        isCalibrated = true;
      }
    }
    else
    {
      if (!audioAmp.isRunning())
      {
        moistureCalibrationStep = moistureSensorCalibration(moistureCalibrationStep);
      }
    }
  }
}

/***************************************************
   Function: void ambientLightSensorHandler(void)
   Summary: The function handles the ambient light
   sensor related tasks
   Input: None
   Output: None
 ***************************************************/
void ambientLightSensorHandler(void)
{

  if ((currentTime - ambientLightCheckTime) > AL_CHECK_TIME_INTERVAL)
  {
    currentLight = 0;
    //Collect samples
    currentLight = al_readSensor();
    //Map the samples to percent based on calibrated data
    //currentLight = map(currentLight, 0, AMBIENT_LIGHT_MAX, 0, 100);
    currentLight = 100 * (log(currentLight + 1) / log(AMBIENT_LIGHT_MAX));
    //Make sure the percent is within 0 to 100 percent
    if (currentLight < 0)
    {
      currentLight = 0;
    }
    if (currentLight > 100)
    {
      currentLight = 100;
    }
    Serial.print("Light: ");
    Serial.println(currentLight);
    if (firstLightMeasurement)
    {
      char lightDataToSave[10] = {0};
      appendFile(SD, "/webPage/measuredData/lightData.txt",  itoa(currentLight, lightDataToSave, 10));
      appendFile(SD, "/webPage/measuredData/lightData.txt", "\n");
      firstLightMeasurement = false;
    }
    ambientLightCheckTime = currentTime;
  }
}

/***********************************************
   Function: void batteryMonitorHandler(void)
   Summary: The function handles the battery
   monitoring related tasks
   Input: None
   Output: None
 ***********************************************/
void batteryMonitorHandler(void)
{

  if ((currentTime - batteryMonitorCheckTime) > BAT_CHECK_TIME_INTERVAL)
  {
    currentBattery = 0;
    //Collect samples
    currentBattery = batteryMonitorReadAverage(CALIBRATION_SAMPLE_SIZE);
    //Map the samples to percent based on calibrated data
    currentBattery = map(currentBattery, BAT_ADC_MIN, BAT_ADC_MAX, 0, 100);
    //Make sure the percent is within 0 to 100 percent
    if (currentBattery < 0)
    {
      currentBattery = 0;
    }
    if (currentBattery > 100)
    {
      currentBattery = 100;
    }
    Serial.print("Battery: ");
    Serial.println(currentBattery);
    if (firstBatteryMeasurement)
    {
      char batteryDataToSave[10] = {0};
      appendFile(SD, "/webPage/measuredData/batteryData.txt",  itoa(currentBattery, batteryDataToSave, 10));
      appendFile(SD, "/webPage/measuredData/batteryData.txt", "\n");
      firstBatteryMeasurement = false;
    }
    if (currentBattery < batteryThreshold)
    {
      setLedRGB(100, 0, 0);
    }
    batteryMonitorCheckTime = currentTime;
  }
}
/**********************************************************************************
   Function: int batteryMonitorReadAverage(int NUMBER_OF_SAMPLES_TO_AVERAGE)
   Summary: The function takes a number of samples and averages them together
   Input: The total number of samples to average
   Output: The averaged of the samples taken
 **********************************************************************************/
int batteryMonitorReadAverage(int NUMBER_OF_SAMPLES_TO_AVERAGE)
{
  digitalWrite(BATTERY_MEASURE_EN_PIN, HIGH);
  int avgBatteryReading = 0;
  for (int i = 0; i < NUMBER_OF_SAMPLES_TO_AVERAGE; i++)
  {
    avgBatteryReading += analogRead(BATTERY_MEASURE_PIN);
  }
  avgBatteryReading /= NUMBER_OF_SAMPLES_TO_AVERAGE;
  digitalWrite(BATTERY_MEASURE_EN_PIN, LOW);
  return avgBatteryReading;
}

void setLedRGB(uint8_t RED, uint8_t GREEN, uint8_t BLUE)
{
  digitalWrite(LED_LEVEL_SHIFTER_EN_PIN, HIGH);
  leds[0] = CRGB(RED, GREEN, BLUE);
  FastLED.show();
  digitalWrite(LED_LEVEL_SHIFTER_EN_PIN, LOW);
}
/*******************************************
   Function: void sleepHandler(void)
   Summary: The function handles the sleep
   related tasks
   Input: None
   Output: None
 *******************************************/
void sleepHandler(void)
{
  if (readyToSleep && !audioAmp.isRunning() && !wifiRequired && !buttonDebouncing)
  {
    Serial.println("Going to sleep");
    readyToSleep = false;
    al_off();
    digitalWrite(I2S_EN_PIN, LOW);
    setLedRGB(0, 0, 0);
    delay(250);
    esp_deep_sleep_start();
  }
}
/******************************************
   Function: void wifiTaskHandler(void)
   Summary: The function handles the WiFi
   related tasks, like initializing the
   radio and running the captive portal
   Input: None
   Output: None
 ******************************************/
void wifiTaskHandler(void)
{
  if (wifiRequired)
  {
    dnsServer.processNextRequest();
    if (!wifiInitialized)
    {
      Serial.println("Initializing WiFi");
      setLedRGB(0,0,100);
      WiFi.softAP("realPlantNursery");
      dnsServer.start(53, "*", WiFi.softAPIP());
      ws.onEvent(onEvent);
      server.addHandler(&ws);
      server.addHandler(new captivePageHandler());
      server.begin();
      wifiInitialized = true;
      wifiTimeoutTime = currentTime;
    }
  }
  else
  {
    if (wifiInitialized)
    {
      dnsServer.stop();
      server.end();
      WiFi.disconnect(true);
      WiFi.mode(WIFI_OFF);
      wifiInitialized = false;
      setLedRGB(0,0,0);
    }
  }
  if ((currentTime - wifiTimeoutTime) > WIFI_ON_TIMEOUT)
  {
    wifiRequired = false;
  }
}
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

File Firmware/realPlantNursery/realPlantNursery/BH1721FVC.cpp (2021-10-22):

#include <Arduino.h>
#include <Wire.h>
#include "BH1721FVC.h"

void al_rst(int RESET_PIN)
{
  digitalWrite(RESET_PIN, LOW);
  delay(10);
  digitalWrite(RESET_PIN, HIGH);
}

void al_off(void)
{ 
  Wire.beginTransmission(BH1721FVC_ADDRESS);
  Wire.write(BH1721FVC_OFF);
  if(Wire.endTransmission() != 0)
  {
    Serial.println("Error reading from device");
  }
}

void al_on()
{
  Wire.beginTransmission(BH1721FVC_ADDRESS);
  Wire.write(BH1721FVC_ON);
  if(Wire.endTransmission() != 0)
  {
    Serial.println("Error reading from device");
  }
}

void al_setAutoResolution(void)
{
  Wire.beginTransmission(BH1721FVC_ADDRESS);
  Wire.write(BH1721FVC_AUTO_RESOLUTION);
  if(Wire.endTransmission() != 0)
  {
    Serial.println("Error reading from device");
  }
}

void al_setHighResolution(void)
{
  Wire.beginTransmission(BH1721FVC_ADDRESS);
  Wire.write(BH1721FVC_H_RESOLUTION);
  if(Wire.endTransmission() != 0)
  {
    Serial.println("Error reading from device");
  }
}

void al_setLowResolution(void)
{
  Wire.beginTransmission(BH1721FVC_ADDRESS);
  Wire.write(BH1721FVC_L_RESOLUTION);
  if(Wire.endTransmission() != 0)
  {
    Serial.println("Error reading from device");
  }
}

void al_initializeSensor(int RESET_PIN)
{
  al_rst(RESET_PIN);
  al_off();
  al_on();
  al_setAutoResolution();
}

uint16_t al_readSensor(void)
{
  uint8_t msb = 0;
  uint8_t lsb = 0;

  Wire.beginTransmission(BH1721FVC_ADDRESS);
  Wire.requestFrom(BH1721FVC_ADDRESS, (uint8_t)2);
  
  msb = Wire.read(); 
  lsb = Wire.read(); 

  return (((((uint16_t)msb) << 8) | lsb)/1.2);
}
